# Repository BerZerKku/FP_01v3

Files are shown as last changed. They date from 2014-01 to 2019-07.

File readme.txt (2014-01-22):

Плата FP_01v3. 
Cделана в OrCAD 16.6.

Предназначена для использования совместо с АВАНТ всех модификаций работающих
от 220В.

Изменения:
Установлены самовосстанавливающиеся предохранители.
Добавлены демпфирующие цепочки параллельно симфазному дросселю.
Заложена возможность установки варисторов после каждого каскада.

Недостатки:
Варисторы установлены на землю. Которые к тому же периодически выгорают (-ли ?!)
на подстанции.

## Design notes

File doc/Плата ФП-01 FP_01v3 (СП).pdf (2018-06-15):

Напечатано: 15 июня 2018 г. 10:03:28, Щеблыкин Михаил Владимирович
Поз. | Наименование | Корпус | Кол. | Поз. по Э3 | Примечание
| Документация
| Сборочный чертеж 2.140.452 | | 1
| Детали
3 | [FP_01v3] Печатная плата FP_01v3 | | 1
| Прочее
| Клеммы
5 | [DG78R-B-02P-13] Клеммная колодка DG78R-B-02P-13 Degson | 2 | 1 | X2
7 | [DG78R-B-03P-13] Клеммная колодка DG78R-B-03P-13 Degson | 3 | 1 | X1
| Конденсаторы
11 | [DE1B3KX471KA5B] Конденсатор DE1B3KX471KA5B 470pF 250V 10% X1/Y1 Murata | LEAD-2 | 4 | C2, C3, C5, C6
13 | [B32922C3474M] Конденсатор B32922C3474M 305V 0.47uF 20% Epcos | LEAD-2 | 2 | C1, C4
| Предохранители,держатели предохранителей
17 | [LVR200S] Предохранитель LVR200S 240V 2A TE | LEAD-2 | 2 | FU1, FU2
| Дроссели, фильтры, катушки индуктивности
21 | [SH260C-5.0-50] Индуктивность SH260C-5.0-50 5A 50uH 20% Talema | LEAD-2 | 2 | L1, L2 | Допустимые замены: [P0848NL] Индуктивность P0848NL 5A 50uH 20% Pulse

2.140.452

4 | Лист | № докум | Подп. | Дата
Разраб. | Щеблыкин М.В. | | 01.08.2014 | ФП-01 v1.3 (Плата FP_01v3) | Лит. | Лист | Листов
Провер. | Вершинин А.С. | | 01.08.2014 | | | 1 | 3
Т.контр. | Бокова Т.И. | | 01.08.2014 | | Прософт-Системы
Н.контр. | Назаренко А.Н. | | 01.08.2014
Утв. | Чирков А.Г. | | 01.08.2014

Поз. | Наименование | Корпус | Кол. | Поз. по Э3 | Примечание
23 | [B82725A2402N001] Индуктивность B82725A2402N001 EPCOS | LEAD-4 | 1 | L3
| Резисторы
27 | [B72220S0421K101] Варистор | LEAD-2 | 4 | RU1-RU4
| B72220S0421K101 680VDC/420VAC 20mm Epcos
29 | [JVR-20N391K] Варистор JVR-20N391K 390V 20mm 10% | LEAD-2 | 1 | RU5
31 | [MF-2-56-5%] Резистор MF-2 56 5% | LEAD-2 | 2 | R1, R2
| Диоды,светодиоды,супрессоры,стабилитроны
35 | [1.5SMC300CA] Диод 1.5SMC300CA SMC | DO-214 AB | 2 | VD1, VD2
| | | | | 2.140.452 | Лист 2 Изм
4
| Лист | № докум | Подп. | Дата

Лист регистрации ревизий

№ ревизии | № замененных (измененных) страниц | Дата ревизии | Краткое содержание и причина внесения изменений | Примечание
0 | | 05.12.16
2 | | 05.12.16
3 | | 24.05.18 | Добавлена замена для индуктивности SH260C (поз.21). СП формируется из 1С, поз. обозначения СБ приведены в соответсвие новой СП. | Егорова Елена Игоревна
4 | | 04.06.18 | P0848NL перенесен в замену для поз.21. | Егорова Елена Игоревна

2.140.452

3
4
Лист Изм. | Лист | № докум. | Подп. | Дата

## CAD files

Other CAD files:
doc/Плата ФП-01 FP_01v3 (СБ).dwg

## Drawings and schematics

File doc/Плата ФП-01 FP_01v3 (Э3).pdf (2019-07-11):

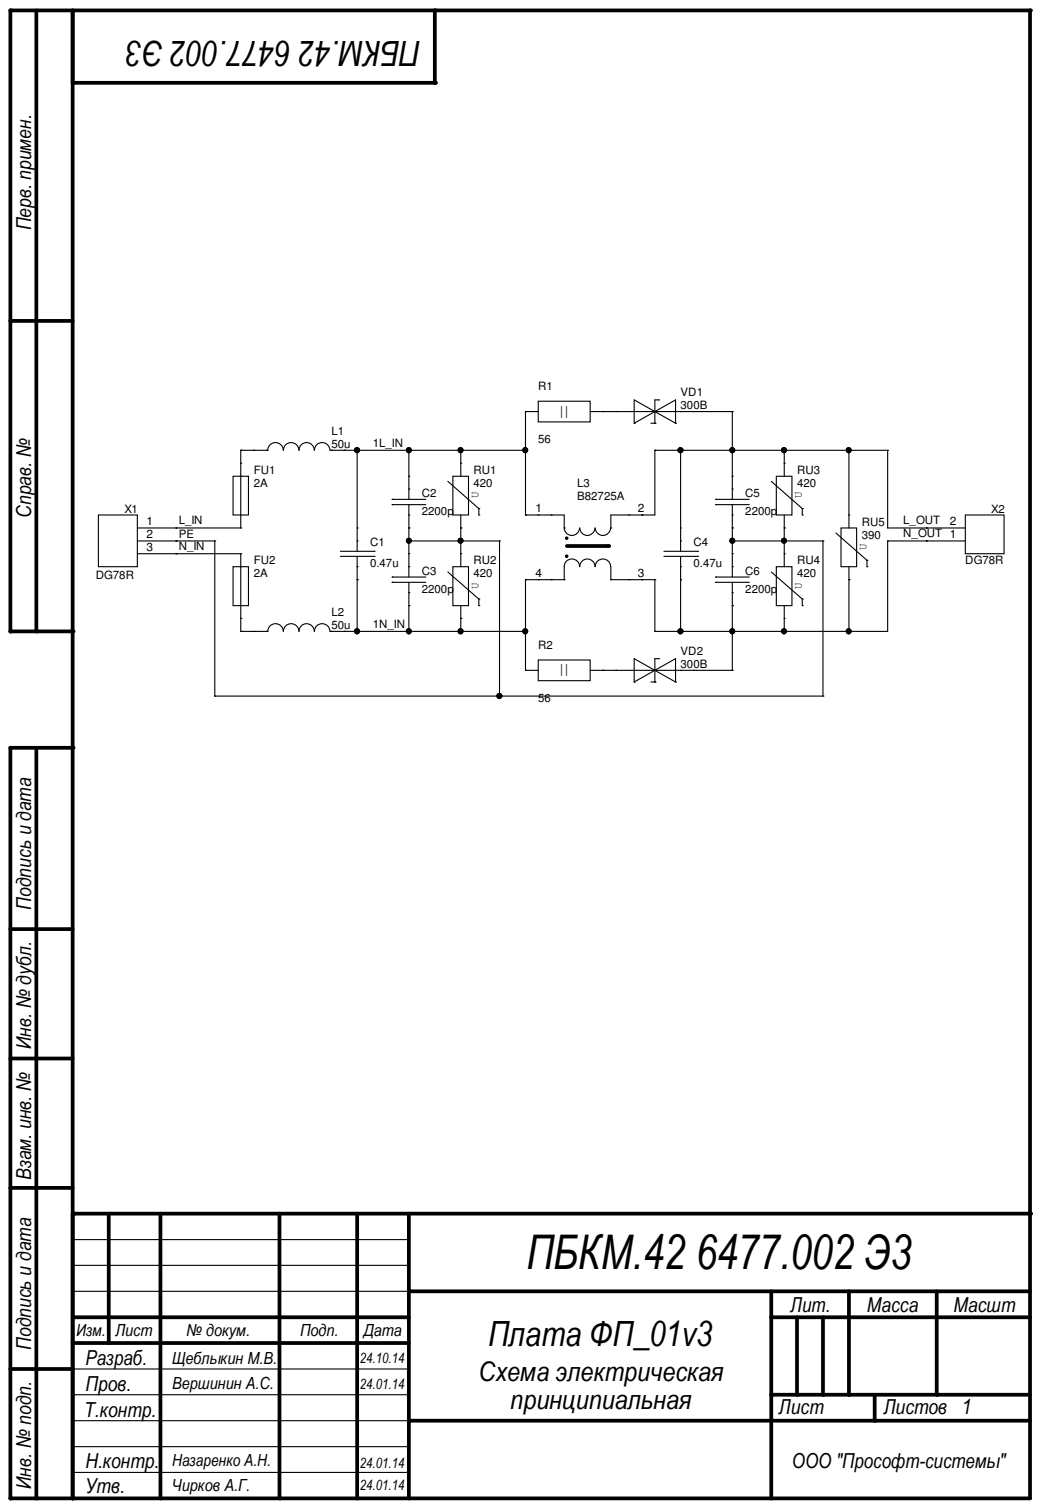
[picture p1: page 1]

Инв. № подп. Подпись и дата Взам. инв. № Инв. № дубл. Подпись и дата

ПБКМ.42 6477.002 Э3

Плата ФП_01v3 Схема электрическая принципиальная | Лит. | Масса | Масшт

Изм. | Лист | № докум. | Подп. | Дата
Разраб. | | Щеблыкин М.В. | | 24.10.14
Пров. | Вершинин А.С. | | 24.01.14
Т.контр. | | | | | Лист | Листов 1

Н.контр. | Назаренко А.Н. | 24.01.14
Утв. | Чирков А.Г. | 24.01.14

ООО "Прософт-системы"

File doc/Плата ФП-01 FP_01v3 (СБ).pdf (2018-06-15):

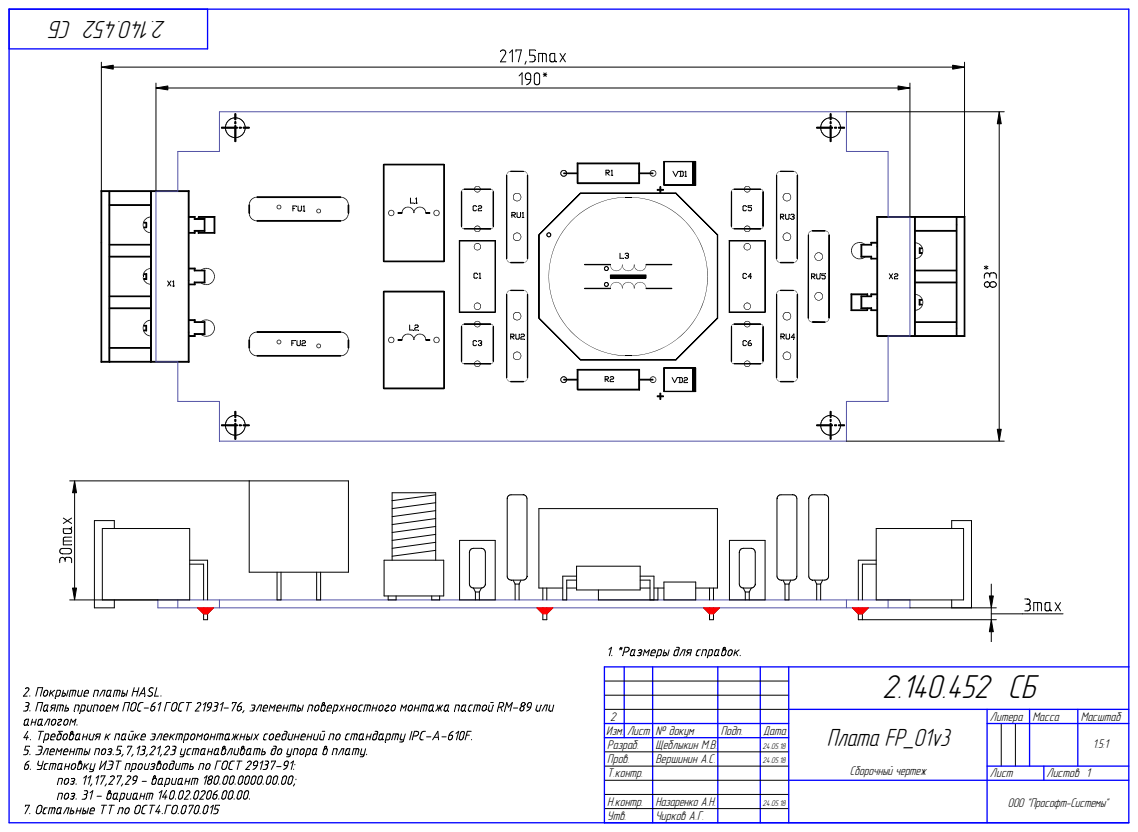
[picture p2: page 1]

2 | | | | Ïëàòà FP_01v3 Ñáîðî÷íûé ÷åðòåæ | Ëèòåðà | Ìàññà | Ìàñøòàá
Èçì. Ëèñò | № äîêóì | Ïîäï. | Äàòà | | | | | 1.5:1
Ðàçðàá. | Ùåáëûêèí Ì.Â. | | 24.05.18
Ïðîâ. | Âåðøèíèí À.Ñ. | | 24.05.18
Ò.êîíòð. | | | | Ëèñò | Ëèñòîâ 1

Í.êîíòð. | Íàçàðåíêî À.Í. | 24.05.18
Óòâ. | ×èðêîâ À.Ã.

ÎÎÎ "Ïðîñîôò-Ñèñòåìû"

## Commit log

2014-01-22 Вновь.
    [FP_01V3.DSN, fp_01v3.brd]
2014-01-22 Сделана разводка.
    [FP_01V3.DSN, fp_01v3.brd]
2014-01-23 Резистор в демпферной цепи заменен на 2Вт, а супрессор поставлен на большую мощность. Подготовлены файлы заказа.
    [FP_01V3.DSN, art_param.txt, fp_01v3.brd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]
2014-01-24 На схеме сделано вариантное исполнение. Вариант 1 - полный, кондеры на землю 470пФ. Вариант 2 - нет второго каскада, кондеры на землю 2200пФ. Сделана СП на плату.
    [FP_01V3.DSN, Плата ФП-01 FP_01v3 (СБ).dwg]
2014-01-24 Добавлен СБ. Документ проверен Назаренко.
    [Плата ФП-01 FP_01v3 (СБ).dwg]
2014-05-16 Убрано вариантное исполнение. Плата запаивается полностью.
2014-06-30 СП рев.2 СБ рев.1 Из пункта 5 ТТ убрана поз.23.
    [Плата ФП-01 FP_01v3 (СБ).dwg]
2018-06-15 СП rev.4 СБ rev.2 СП перенесена в 1С. В СБ ТТ исправлены для соответствия новой СП.
    [Плата ФП-01 FP_01v3 (СБ).dwg]
2019-07-11 Добавить схему Э3.
